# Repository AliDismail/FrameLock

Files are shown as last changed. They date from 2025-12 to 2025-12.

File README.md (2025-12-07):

# FrameLock

## About

FrameLock is a lightweight autonomous mobile robot designed to act as a smart camera operator and mobile assistant, integrating real-time face tracking, automatic centering, and adaptive motion.  
This project proposes the design of a lightweight autonomous mobile robot that acts as both a smart camera operator and a mobile carrying  
assistant.
It integrates real-time face tracking, automatic centering, and smooth mobility to follow the user without any manual control.

---

## Versions

### Version 1

-   Autonomous subject tracking and centering using face recognition
-   Mobile platform capable of carrying items (equipment, tools, camera gear…)
-   Adaptive by maintaining distance & adjusting speed
-   Stable motion with PID and balanced chassis design
-   Fully standalone system that requires no intervention
-   Sleek and rigid design for portability

### Version 2 (Work in Progress)

- Current development branch focuses on implementing a low level PID controller on each motor to ensure correct input to output behavior.
- Goal: improve stability
- Work in progress: adapting the machine logic and hardware include the digital encoder for each motor
- Not yet fully documented or tested.

## Status

- ✅ Version 1  complete and documented.
- 🚧 Version 2  under development.

---

## Team Members

- Version 1: Ali Ismail, Nour Zebian, Farah Mikheal
- Version 2: Ali Ismail, Nour Zebian, Farah Mikheal

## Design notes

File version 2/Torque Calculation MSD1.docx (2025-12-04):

# Torque Calculation for 6 kg Robot on Tiles

Estimating the required torque for robot’s displacement to be close to human pace while tracking, we used:

• Mass m = 6 kg

• Ground: flat terrain

• Number of driven wheels = 2

• Wheel radius r = 0.065 m (130 mm diameter)

• Chosen linear acceleration a ≈ 0.3 m/s²

1. Acceleration force:

F_acc = m · a = 6 × 0.3 = 1.8 N

2. Rolling resistance on tiles (C_rr ≈ 0.02):

F_rr = C_rr · m · g = 0.02 × 6 × 9.81 ≈ 1.18 N

3. Total drive force:

F_total ≈ F_acc + F_rr ≈ 1.8 + 1.18 ≈ 3.0 N

4. Torque at the wheels:

T_total = F_total · r = 3.0 × 0.065 ≈ 0.195 N·m

5. Torque per motor (with 2 driven wheels):

T_per_motor ≈ T_total / 2 ≈ 0.195 / 2 ≈ 0.0975 N·m ≈ 0.1 N·m

Therefore, each motor should be able to provide about 0.1 N·m of continuous torque. For this, we selected the motors with a safety factor of around 2, this value as stall torque to ensure a safe margin.

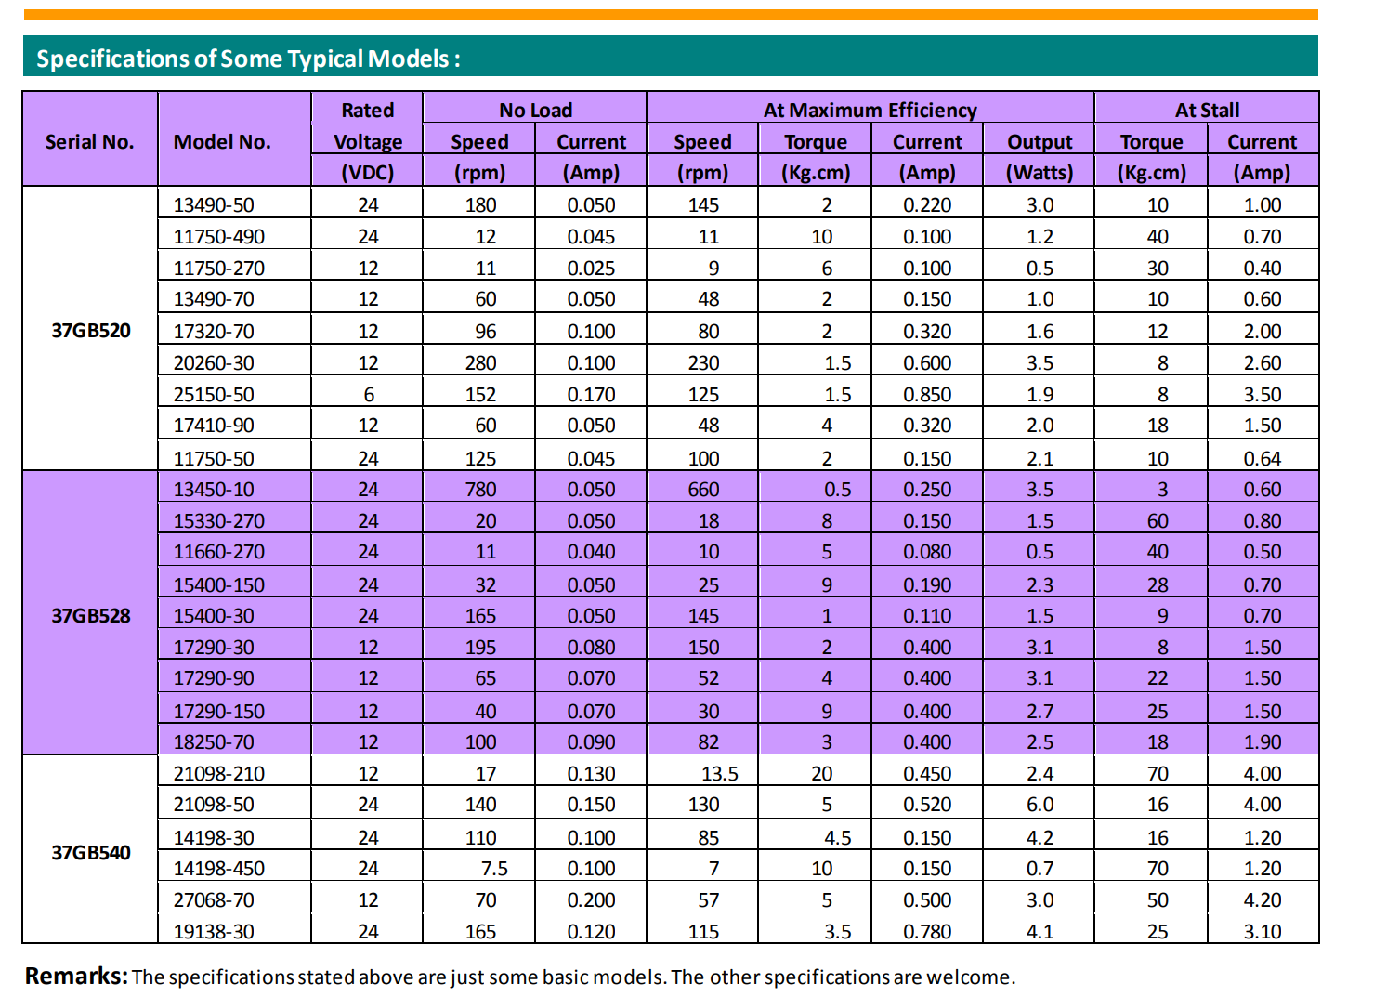
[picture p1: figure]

PWM duty (d) | Approx. torque (T(d))
30% | 0.059 N·m
40% | 0.078 N·m
50% | 0.098 N·m (just below required)
60% | 0.118 N·m
70% | 0.137 N·m
80% | 0.157 N·m
90% | 0.176 N·m
100% | 0.196 N·m

We need around 0.1N.m

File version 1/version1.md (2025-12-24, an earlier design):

# FrameLock

## Introduction

Capturing smooth video shots is challenging, especially when filming solo. FrameLock is a lightweight autonomous mobile robot designed to act as a smart camera operator and mobile assistant, integrating real-time face tracking, automatic centering, and adaptive motion.  
This project proposes the design of a lightweight autonomous mobile robot that acts as both a smart camera operator and a mobile carrying  
assistant.
It integrates real-time face tracking, automatic centering, and smooth mobility to follow the user without any manual control.

The robot:

- Autonomous subject tracking and centering using face recognition
- Mobile platform capable of carrying items (equipment, tools, camera gear…)
- Adaptive by maintaining distance & adjusting speed
- Stable motion with PID and balanced chassis design
- Fully standalone system that requires no intervention
- Sleek and rigid design for portability

---

## Equipment

- MG90S servo motor
- Arduino kit remote control
- IR receiver module
- Arduino UNO R3
- Raspberry Pi 5 8GB ram
- L298N motor driver
- 37GB528 DC motor
- WS2812B RGB Neopixel LED Ring
- GY-30 BH1750 intensity light sensor
- Raspberry Pi5 official case
- Type C 5V/5A output power bank

---

## Design Summary

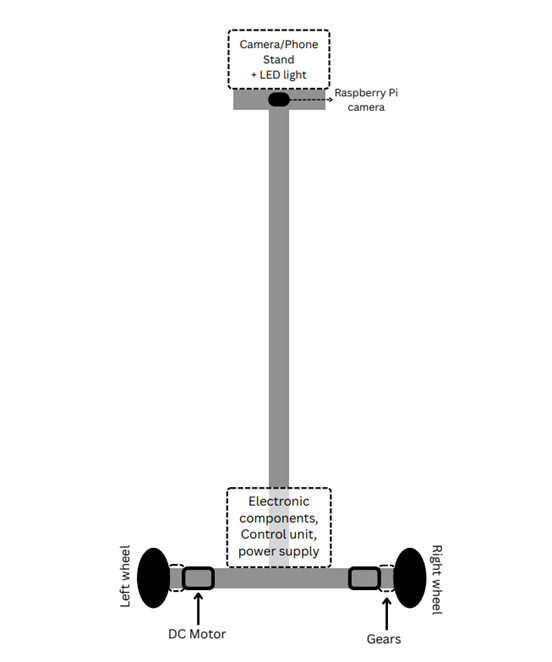
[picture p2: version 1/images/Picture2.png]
Figure 1: Theoretical Concept


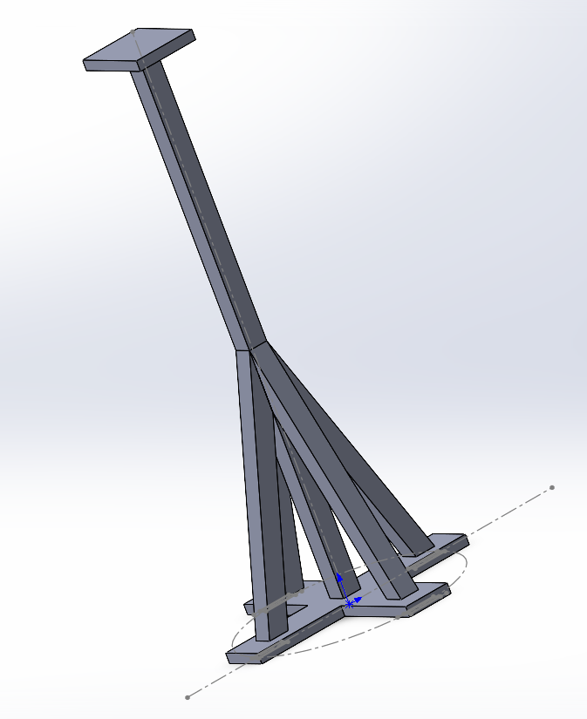
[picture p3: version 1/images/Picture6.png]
Figure 2: CAD Prototype


Our project is lightweight autonomous mobile tripod robot that can:

- Recognize authorized faces
- Choose the face to follow
- Center the face and the camera
- Maintain a certain distance between the camera and the face

---

## System Details

Our design went through many theoretical solutions and we choose an optimal solution out of them after testing in simulations which one we should use.
The solution we choose highlighted in the table:
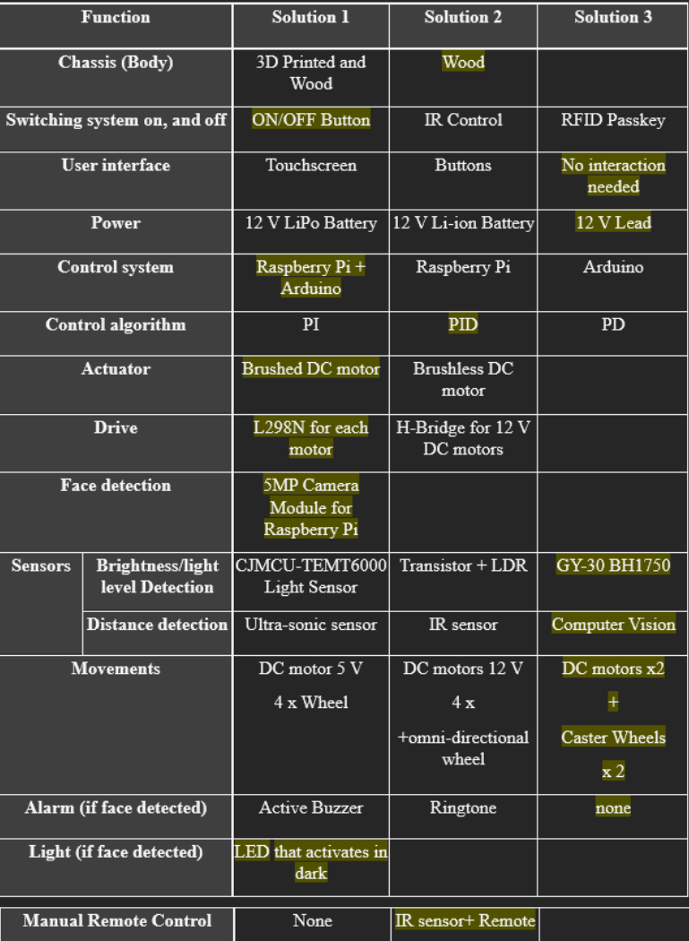
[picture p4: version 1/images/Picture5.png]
Figure 3: Optimal Solution Table

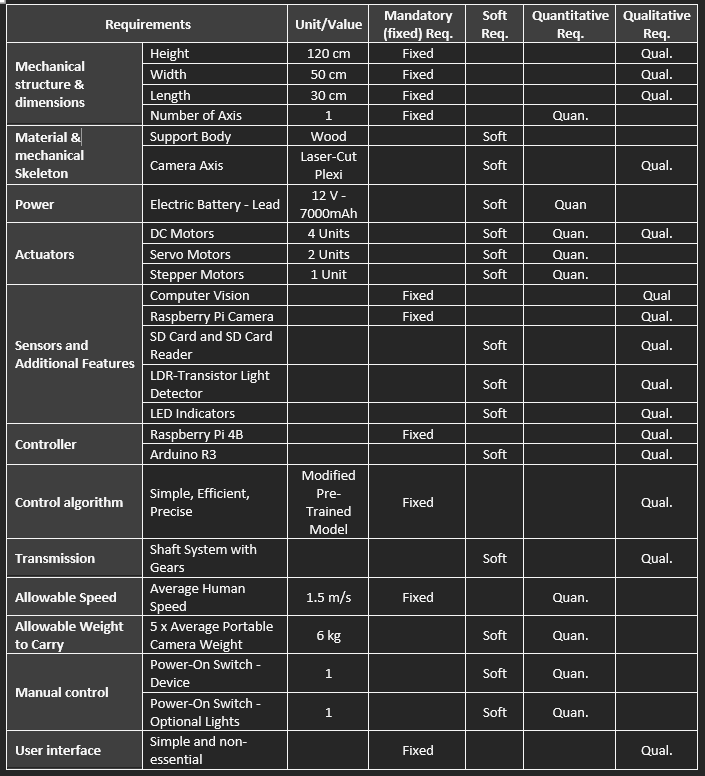
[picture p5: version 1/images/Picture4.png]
Figure 3.5: Optimal Solution Table


### Design

- **Main Body**: Constructed from wood to provide a strong yet lightweight frame, with an integrated compartment dedicated to housing the battery.
- **Electronics Housing**: A custom case was fabricated for both the power bank and the Raspberry Pi 5. Reinforced cardboard was used for durability, and the case was securely mounted onto the wooden structure.
- **Wiring System**: Extended custom-built wiring harnesses (female-to-male and female-to-female connectors) were created to bridge the long distance between the Raspberry Pi and the motors, ensuring reliable connectivity and flexibility in component placement.

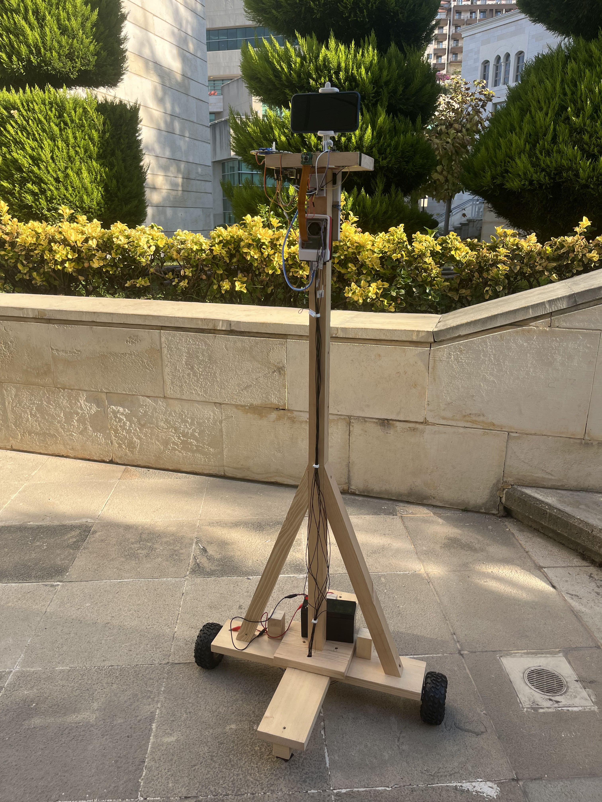
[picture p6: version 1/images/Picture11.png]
Figure 4: Main Body


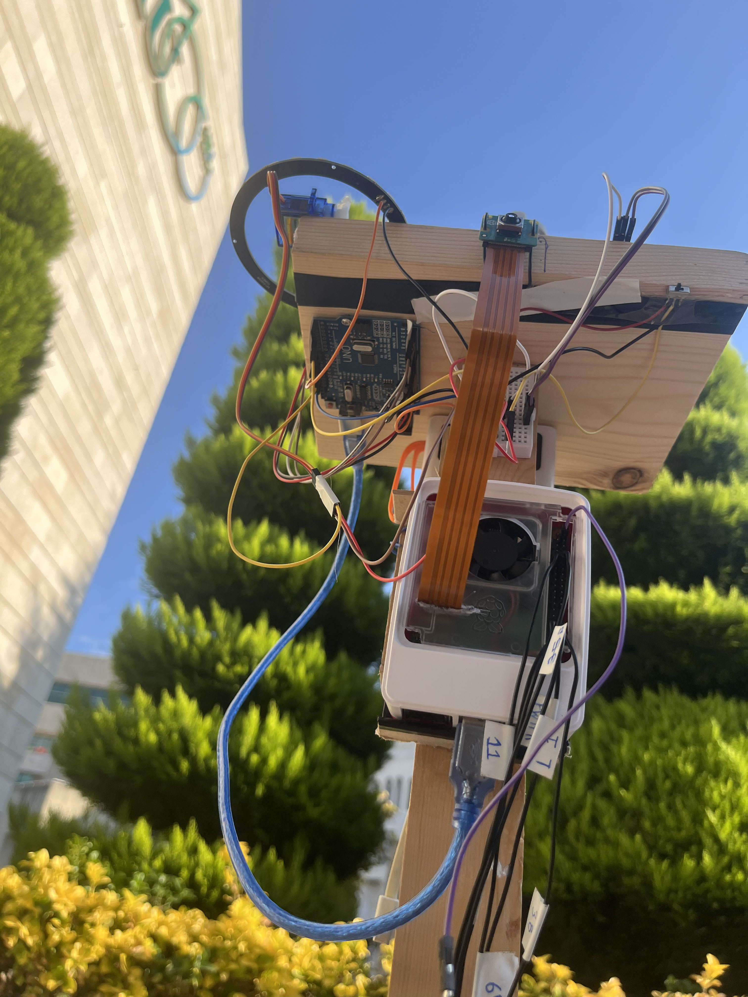
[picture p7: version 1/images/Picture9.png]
Figure 5: Pi5 Case


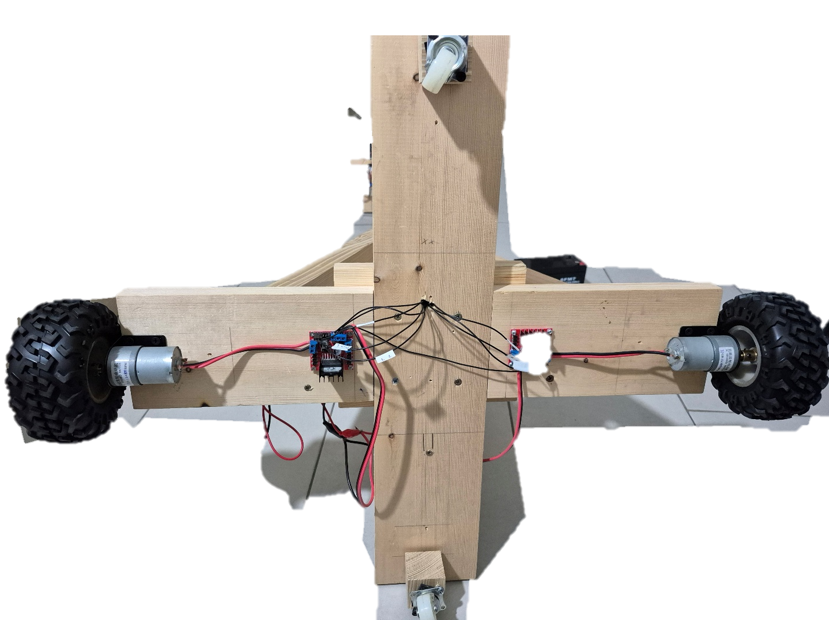
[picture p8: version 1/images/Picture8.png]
Figure 6: Motor Setup


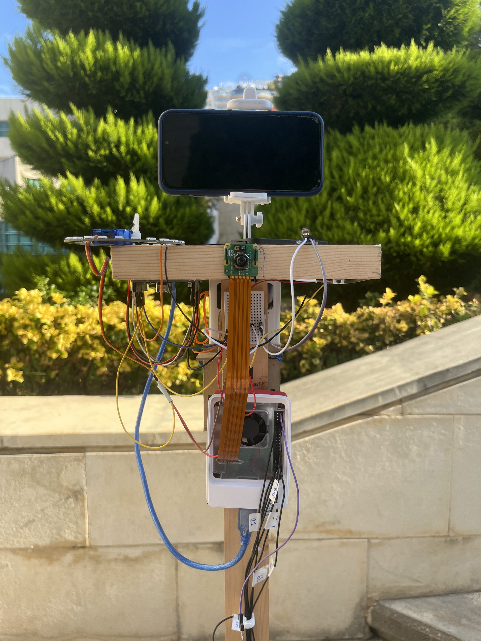
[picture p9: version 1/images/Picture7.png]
Figure 7: Arduino Setup


### Circuit

**Pi5 Connections:**

- DC motor 1 + L298N motor driver 1
  - IN1: GPIO16 | pin 36
  - IN2: GPIO 17 | pin 11
  - ENB: GPI 18 | pin 12
- DC motor 2 + L298N motor driver 2
  - IN1: GPIO16 | pin 36
  - IN2: GPIO 17 | pin 11
  - ENB: GPI 18 | pin 12
- Pi camera
- Arduino | USB A port

**Arduino Connections**

- Servo motor | pin 9
- LED ring | pin 6
- IR receiver | pin 11

---

## Code

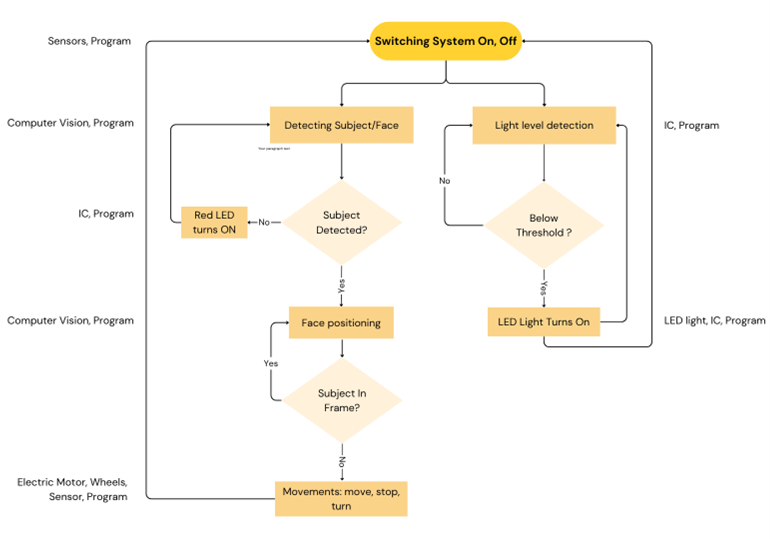
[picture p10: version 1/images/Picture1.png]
Figure 8: Logic Diagram


The robot’s behavior is governed by a structured loop that integrates **IR input**, **computer vision**, and **motor control**:

### Control Logic

1.  **User Input Phase**
    - The system waits for a command via the IR receiver, specifying which face to track.
2.  **Centering Phase**
    - Once the face is identified, the robot continuously adjusts its orientation to align the face with the center of the camera’s field of view using a PID algorithm.
3.  **Distance Maintenance Phase**
    - When the face is centered, the robot regulates its position to maintain a predefined distance between the camera and the subject using a PID algorithm.
    - If the face drifts off-center, the robot re-enters the centering phase before resuming distance regulation.

### Note

To run the code you need to write this commands in the terminal:

1. Create a virtual environment
   ```
   python3 -m venv face_rec
   ```
2. Place the requirements file inside the venv you created
3. download the libraries using the requirements file
   ```
   source  face_rec/bin/activate
   pip install -r requirements.txt
   ```

---

## Team Members

Ali Ismail - Control System, CV & Integration, Arduino Development

Farah Michael - Mechanical Design, Arduino Development

Nour Zebian - Mechanical Design, CV & Integration

## Sources
Demo Video:
https://youtube.com/shorts/7iFiCQCnec0

PID Controller Library:

- Motor Speed Controller:
  https://thingsdaq.org/2022/04/17/motor-speed-control-with-raspberry-pi/
- Gpiozero Extended Library:
  https://github.com/EduardoNigro/Things-DAQ-Code/blob/main/Motor-Speed-Control/gpiozero_extended.py

Facial Recognition with OpenCV:

- Written Tutorial:
  https://core-electronics.com.au/guides/raspberry-pi/face-recognition-with-raspberry-pi-and-opencv/
- YouTube Tutorial:
  https://www.youtube.com/watch?v=3TUlJrRJUeM

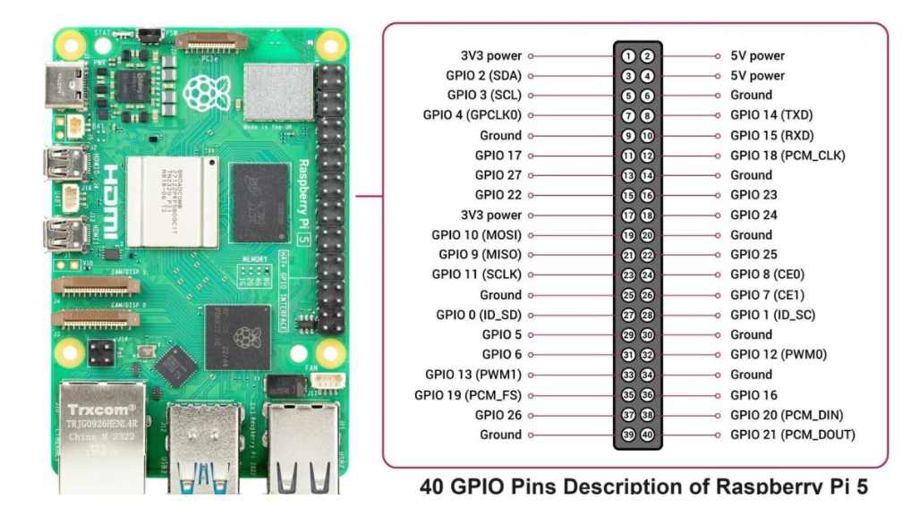
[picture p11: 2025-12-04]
version 2/datasheet/pins.png

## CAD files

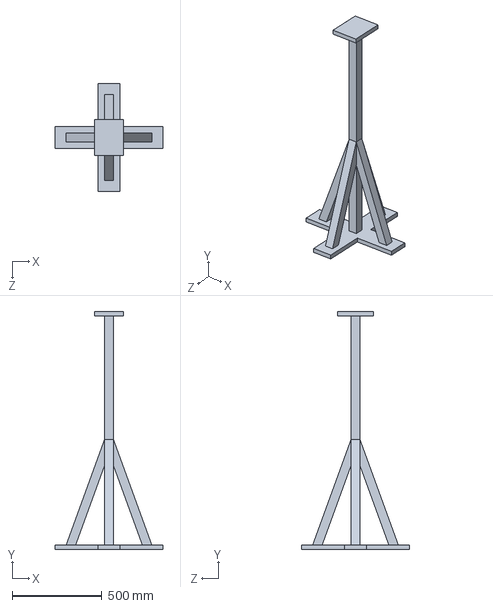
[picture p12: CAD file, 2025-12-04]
version 2/design/MSD1 project.SLDPRT
600.0 x 1325.0 x 600.0 mm

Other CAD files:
version 1/design/MSD1 project.SLDDRW
version 2/design/MSD1 project.SLDDRW

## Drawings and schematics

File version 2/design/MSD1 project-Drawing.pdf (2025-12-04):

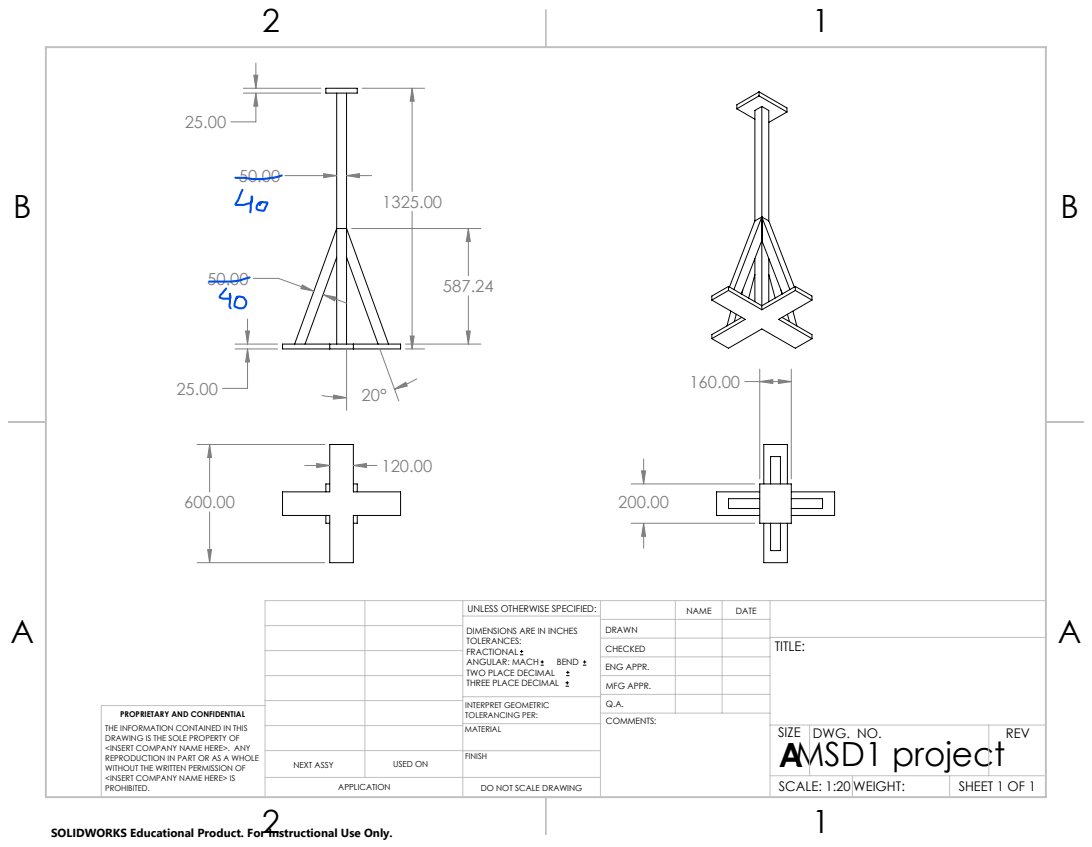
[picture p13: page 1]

UNLESS OTHERWISE SPECIFIED: | | NAME | DATE
DIMENSIONS ARE IN INCHES TOLERANCES: FRACTIONAL ANGULAR: MACH BEND TWO PLACE DECIMAL THREE PLACE DECIMAL | DRAWN

CHECKED | | | TITLE:

ENG APPR.
MFG APPR.

INTERPRET GEOMETRIC TOLERANCING PER: | Q.A.
MATERIAL | | SIZE A MSD1 project | DWG. NO. | REV

PROPRIETARY AND CONFIDENTIAL
THE INFORMATION CONTAINED IN THIS
DRAWING IS THE SOLE PROPERTY OF
<INSERT COMPANY NAME HERE>. ANY
REPRODUCTION IN PART OR AS A WHOLE
WITHOUT THE WRITTEN PERMISSION OF
<INSERT COMPANY NAME HERE> IS
PROHIBITED.

NEXT ASSY | USED ON | FINISH

APPLICATION | DO NOT SCALE DRAWING | | SCALE: 1:20 WEIGHT: | | SHEET 1 OF 1

SOLIDWORKS Educational Product. For Instructional Use Only.

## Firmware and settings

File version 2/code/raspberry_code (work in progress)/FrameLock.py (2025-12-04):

import face_recognition
import cv2
import numpy as np
from picamera2 import Picamera2
import time
import pickle
import threading
import serial
from gpiozero_extended import Motor, PID

# List of names that will trigger the GPIO pin (case-sensitive)
authorized_names = ["Ali Ismail", "Nour Zebian", "Farah Micheal", "Maher AlRafei"]

# Map IR keys to names (edit to match your encodings.pickle order or preferences)
IR_BUTTON_TO_NAME = {
    "KEY_0": "Ali Ismail",
    "KEY_1": "Nour Zebian",
    "KEY_2": "Farah Micheal",
    "KEY_3": "Maher AlRafei",
    # extend as needed:
    # "KEY_4": "Someone Else",
    # "KEY_5": "...",
    # ...
}

# ------------------------------
# Serial IR selector (Arduino → Pi)
# ------------------------------
class SerialIRSelector:
    def __init__(self, tracker, port="/dev/ttyUSB0", baud=9600):
        self.tracker = tracker
        self.port = port
        self.baud = baud
        self._stop = threading.Event()
        self._thread = None
        self._ser = None

    def start(self):
        try:
            self._ser = serial.Serial(self.port, self.baud, timeout=0.1)
            print(f"[IR] Connected to {self.port} @ {self.baud}")
        except Exception as e:
            print(f"[IR][WARN] Could not open serial port {self.port}: {e}")
            self._ser = None
            return

        self._thread = threading.Thread(target=self._loop, daemon=True)
        self._thread.start()

    def _loop(self):
        while not self._stop.is_set():
            try:
                if self._ser and self._ser.in_waiting > 0:
                    code = self._ser.readline().decode(errors="ignore").strip()
                    if code:
                        # Expecting strings like "KEY_0" .. "KEY_9" from Arduino
                        if code in IR_BUTTON_TO_NAME:
                            target = IR_BUTTON_TO_NAME[code]
                            self.tracker.set_target(target)
                            print(f"[IR] {code} → target set: {target}")
                        else:
                            print(f"[IR] Unmapped code: {code}")
            except Exception as e:
                print(f"[IR][ERR] Serial read error: {e}")
                time.sleep(0.1)
            time.sleep(0.01)

    def stop(self):
        self._stop.set()
        if self._thread:
            self._thread.join(timeout=1.0)
        if self._ser:
            try:
                self._ser.close()
            except:
                pass


# ------------------------------
# Vision: face detection + distance + overlay
# ------------------------------
class FaceLocation:
    def __init__(self,
                 encoding_file="encodings.pickle",
                 tolerance=0.1,
                 target_face_height_norm=0.25,
                 distance_tolerance_norm=0.03,
                 reference_distance_m=1.0,
                 cv_scaler=4):
        self.tolerance = tolerance
        self.TARGET_FACE_HEIGHT_NORM = target_face_height_norm
        self.DISTANCE_TOLERANCE_NORM = distance_tolerance_norm
        self.REFERENCE_DISTANCE_M = reference_distance_m
        self.cv_scaler = cv_scaler

        print("[INFO] loading encodings...")
        with open(encoding_file, "rb") as f:
            data = pickle.loads(f.read())
        self.known_face_encodings = data["encodings"]
        self.known_face_names = data["names"]

        self.picam2 = Picamera2()
        self.picam2.configure(self.picam2.create_preview_configuration(
            main={"format": 'XRGB8888', "size": (1920, 1080)}
        ))
        self.picam2.start()

        self.face_locations = []
        self.face_names = []
        self.target_name = None  # chosen face to follow

    def set_target(self, name):
        """Choose which face to follow by name."""
        if name in self.known_face_names:
            self.target_name = name
            print(f"[INFO] Target face set to: {name}")
        else:
            print(f"[WARN] {name} not in known faces. Known: {self.known_face_names}")

    def clear_target(self):
        self.target_name = None
        print("[INFO] Target face cleared")

    def process_frame(self, frame):
        resized = cv2.resize(frame, (0, 0), fx=1/self.cv_scaler, fy=1/self.cv_scaler)
        rgb = cv2.cvtColor(resized, cv2.COLOR_BGR2RGB)

        self.face_locations = face_recognition.face_locations(rgb)
        encodings = face_recognition.face_encodings(rgb, self.face_locations)

        self.face_names = []
        for encoding in encodings:
            matches = face_recognition.compare_faces(self.known_face_encodings, encoding)
            name = "Unknown"
            if matches:
                distances = face_recognition.face_distance(self.known_face_encodings, encoding)
                best = np.argmin(distances)
                if matches[best]:
                    name = self.known_face_names[best]
            self.face_names.append(name)

    def get_distance_from_camera(self, frame):
        results = []
        h, w = frame.shape[:2]
        for (top, right, bottom, left), name in zip(self.face_locations, self.face_names):
            top *= self.cv_scaler
            bottom *= self.cv_scaler
            face_height = bottom - top
            norm_height = face_height / h
            safe_height = max(norm_height, 1e-6)
            distance_m = self.REFERENCE_DISTANCE_M * (self.TARGET_FACE_HEIGHT_NORM / safe_height)

            if safe_height < (self.TARGET_FACE_HEIGHT_NORM - self.DISTANCE_TOLERANCE_NORM):
                state = "FAR"
            elif safe_height > (self.TARGET_FACE_HEIGHT_NORM + self.DISTANCE_TOLERANCE_NORM):
                state = "CLOSE"
            else:
                state = "OK"

            results.append((name, distance_m, state))
        return results

    def get_recognized_names(self):
        if self.target_name:
            return [name for name in self.face_names if name == self.target_name]
        else:
            return [name for name in self.face_names if name in authorized_names]

    def get_face_deviation(self, frame):
        """Return signed deviation from center [-0.5, +0.5] for the target (or first authorized)."""
        if not self.face_locations:
            return None
        h, w = frame.shape[:2]

        # pick target face if set, else first authorized
        idx = None
        if self.target_name and self.target_name in self.face_names:
            idx = self.face_names.index(self.target_name)
        else:
            for i, nm in enumerate(self.face_names):
                if nm in authorized_names:
                    idx = i
                    break
        if idx is None:
            return None

        (top, right, bottom, left) = self.face_locations[idx]
        top *= self.cv_scaler
        right *= self.cv_scaler
        bottom *= self.cv_scaler
        left *= self.cv_scaler
        center_x = (left + right) / 2.0
        norm_x = center_x / w
        deviation = norm_x - 0.5
        return deviation

    def annotate_frame(self, frame):
        h, w = frame.shape[:2]
        mid_x = w // 2
        cv2.line(frame, (mid_x, 0), (mid_x, h), (255, 0, 0), 2)

        for (top, right, bottom, left), name in zip(self.face_locations, self.face_names):
            top *= self.cv_scaler
            right *= self.cv_scaler
            bottom *= self.cv_scaler
            left *= self.cv_scaler

            face_height = bottom - top
            norm_height = face_height / h
            safe_height = max(norm_height, 1e-6)
            distance_m = self.REFERENCE_DISTANCE_M * (self.TARGET_FACE_HEIGHT_NORM / safe_height)

            center_x = (left + right) / 2.0
            norm_x = center_x / w
            deviation = norm_x - 0.5
            if abs(deviation) < self.tolerance:
                position = "CENTER"
            elif deviation < 0:
                position = "LEFT"
            else:
                position = "RIGHT"

            # highlight target in green, authorized in cyan, unknown in red
            if name == self.target_name:
                color = (0, 255, 0)
            elif name in authorized_names:
                color = (255, 255, 0)
            else:
                color = (0, 0, 255)

            cv2.rectangle(frame, (left, top), (right, bottom), color, 2)
            label = f"{name} | {distance_m:.2f}m | {position} ({deviation:.2f})"
            cv2.rectangle(frame, (left, top - 25), (right, top), color, cv2.FILLED)
            cv2.putText(frame, label, (left + 6, top - 6),
                        cv2.FONT_HERSHEY_DUPLEX, 0.6, (255, 255, 255), 1)
        return frame

    def cleanup(self):
        cv2.destroyAllWindows()
        self.picam2.stop()


# ------------------------------
# Motor control for distance (forward/backward)
# ------------------------------
class Motor_Control:
    def __init__(self,
                 left_pins,
                 right_pins,
                 kp, ki, kd,
                 Ts=0.05, tau=0.1,
                 setpoint=1.0, tolerance=1e-3,
                 min_torque=0.35, startup_boost_time=0.15,
                 tracker: FaceLocation = None):
        self.motor_left = Motor(enable1=left_pins[0], pwm1=left_pins[1], pwm2=left_pins[2])
        self.motor_right = Motor(enable1=right_pins[0], pwm1=right_pins[1], pwm2=right_pins[2])

        self.Ts = Ts
        self.pid = PID(Ts, kp, ki, kd, tau=tau)

        self.setpoint = setpoint
        self.tolerance = tolerance
        self.min_torque = min_torque
        self.startup_boost_time = startup_boost_time

        # Reuse the shared tracker to avoid multiple camera instances
        self.tracker = tracker

        self._start_time = time.perf_counter()

    def step_distance_control(self, frame):
        distances = self.tracker.get_distance_from_camera(frame)
        recognized = self.tracker.get_recognized_names()

        if not distances or not recognized:
            print("No target/authorized face detected. Stopping motors.")
            self.motor_left.set_output(0)
            self.motor_right.set_output(0)
            return

        # pick the target’s distance
        name_to_follow = self.tracker.target_name if self.tracker.target_name else recognized[0]
        distance = None
        for nm, dist, _ in distances:
            if nm == name_to_follow:
                distance = dist
                break

        if distance is None:
            self.motor_left.set_output(0)
            self.motor_right.set_output(0)
            return

        error = self.setpoint - distance

        if abs(error) > self.tolerance:
            output = self.pid.control(self.setpoint, distance)

            # Startup boost to overcome static friction
            elapsed = time.perf_counter() - self._start_time
            if elapsed < self.startup_boost_time:
                output = 1.0

            # Minimum torque floor
            if abs(output) < self.min_torque:
                output = self.min_torque * (1 if output >= 0 else -1)

            # Apply forward/backward equally
            self.motor_left.set_output(output)
            self.motor_right.set_output(output)
        else:
            self.motor_left.set_output(0)
            self.motor_right.set_output(0)
            print(f"Target distance {self.setpoint:.2f} m maintained.")


# ------------------------------
# Hybrid controller (centering priority, then distance)
# ------------------------------
class HybridController:
    def __init__(self,
                 left_pins, right_pins,
                 kp_dist, ki_dist, kd_dist,
                 kp_cen, ki_cen, kd_cen,
                 Ts=0.05, tau=0.1, setpoint=1.0,
                 ir_port="/dev/ttyUSB0"):
        # Shared vision tracker
        self.tracker = FaceLocation()

        # Start IR selector thread
        self.ir_selector = SerialIRSelector(self.tracker, port=ir_port, baud=9600)
        self.ir_selector.start()

        # PID controllers
        self.center_pid = PID(Ts, kp_cen, ki_cen, kd_cen, tau=tau)
        self.distance_ctrl = Motor_Control(left_pins, right_pins,
                                           kp=kp_dist, ki=ki_dist, kd=kd_dist,
                                           Ts=Ts, tau=tau, setpoint=setpoint,
                                           tracker=self.tracker)

        # Direct motor handles
        self.motor_left = self.distance_ctrl.motor_left
        self.motor_right = self.distance_ctrl.motor_right

        # Tolerances and floors
        self.deviation_tolerance = 0.05      # center tolerance (normalized x)
        self.min_spin_floor = 0.40           # spin-in-place floor
        self.center_startup_boost_time = 0.20

        # Timing
        self.Ts = Ts
        self._center_start = time.perf_counter()

    def run(self):
        try:
            while True:
                frame = self.tracker.picam2.capture_array()
                self.tracker.process_frame(frame)

                deviation = self.tracker.get_face_deviation(frame)
                recognized = self.tracker.get_recognized_names()

                if (self.tracker.target_name and self.tracker.target_name not in self.tracker.face_names):
                    print("Target not visible or no authorized face detected.")
                    self.motor_left.set_output(0)
                    self.motor_right.set_output(0)
                elif deviation is not None and abs(deviation) > self.deviation_tolerance:
                    # Centering mode (higher priority)
                    output = self.center_pid.control(0.0, deviation)

                    # Startup boost for centering
                    elapsed_c = time.perf_counter() - self._center_start
                    if elapsed_c < self.center_startup_boost_time:
                        output = 1.0

                    # Minimum spin torque floor
                    if abs(output) < self.min_spin_floor:
                        output = self.min_spin_floor * (1 if output >= 0 else -1)

                    # Spin in place to reduce horizontal error
                    self.motor_left.set_output(-output)
                    self.motor_right.set_output(output)
                else:
                    # Distance maintaining mode
                    self.distance_ctrl.step_distance_control(frame)

                # Show annotated feed
                annotated = self.tracker.annotate_frame(frame)
                cv2.imshow("Hybrid Face Tracking (IR-selectable target)", annotated)
                if cv2.waitKey(1) & 0xFF == ord('q'):
                    break

                time.sleep(self.Ts)
        finally:
            # Safe shutdown
            self.motor_left.set_output(0)
            self.motor_right.set_output(0)
            self.ir_selector.stop()
            self.tracker.cleanup()
            cv2.destroyAllWindows()


# ------------------------------
# Main: hard-coded values for your 37GB528 + L298N + ~5 kg robot
# ------------------------------
def main():
    # Motor pins (enable1, pwm1, pwm2)
    left_pins = (16, 17, 18)
    right_pins = (19, 20, 21)

    # Control timing and filter
    Ts = 0.05      # 20 Hz control loop (good for vision + L298N)
    tau = 0.10     # derivative low-pass

    # Target distance (meters)
    setpoint = 1.0

    # Distance PID (balanced)
    kp_dist = 0.55; ki_dist = 0.12; kd_dist = 0.04

    # Centering PID (balanced)
    kp_cen = 0.65; ki_cen = 0.15; kd_cen = 0.04

    # Set the serial port to your Arduino (check with ls /dev/ttyUSB* or /dev/ttyACM*)
    ir_port = "/dev/ttyUSB0"

    hybrid_ctrl = HybridController(
        left_pins=left_pins,
        right_pins=right_pins,
        kp_dist=kp_dist, ki_dist=ki_dist, kd_dist=kd_dist,
        kp_cen=kp_cen, ki_cen=ki_cen, kd_cen=kd_cen,
        Ts=Ts, tau=tau, setpoint=setpoint,
        ir_port=ir_port
    )

    print(f"Starting hybrid control with:"
          f" dist(kp={kp_dist}, ki={ki_dist}, kd={kd_dist}),"
          f" cen(kp={kp_cen}, ki={ki_cen}, kd={kd_cen}),"
          f" Ts={Ts}, tau={tau}, setpoint={setpoint}m")
    print("Use IR remote keys (KEY_0..KEY_3) to select target face.")

    try:
        hybrid_ctrl.run()
    finally:
        print("Cleaning up...")

if __name__ == "__main__":
    main()

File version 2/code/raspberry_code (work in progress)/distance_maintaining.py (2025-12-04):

from gpiozero_extended import Motor, PID
import time
from face_distance_tracker import FaceDistanceTracker

class DualMotorDistanceController:
    def __init__(self,
                 left_pins,
                 right_pins,
                 Ts=0.05,
                 kp=0.5, ki=0.1, kd=0.05, tau=0.1,
                 setpoint=1.0, tolerance=1e-3,
                 min_torque=0.5, startup_boost_time=0.1):
        """
        Initialize two motors and PID controller for distance control.
        """
        # Motors
        self.motor_left = Motor(enable1=left_pins[0], pwm1=left_pins[1], pwm2=left_pins[2])
        self.motor_right = Motor(enable1=right_pins[0], pwm1=right_pins[1], pwm2=right_pins[2])

        # PID controller
        self.Ts = Ts
        self.pid = PID(Ts, kp, ki, kd, tau=tau)

        # Target distance and tolerance
        self.setpoint = setpoint
        self.tolerance = tolerance

        # Torque constraints
        self.min_torque = min_torque
        self.startup_boost_time = startup_boost_time

        # Vision tracker
        self.tracker = FaceDistanceTracker()

    def get_camera_distance(self):
        """
        Use FaceDistanceTracker to measure distance in meters.
        Returns the closest face distance, or None if no face.
        """
        frame = self.tracker.picam2.capture_array()
        self.tracker.process_frame(frame)
        distances = self.tracker.get_face_distance(frame)

        if distances:
            # Pick the closest face (largest bounding box height)
            closest = min(distances, key=lambda d: d[1])  # d[1] = distance_m
            name, distance_m, state = closest
            return distance_m
        else:
            return None

    def motor_control_maintaining(self):
        """
        Run dual motor control until error is within tolerance.
        """
        try:
            start_time = time.perf_counter()

            while True:
                distance = self.get_camera_distance()
                if distance is None:
                    print("No face detected. Stopping motors.")
                    self.motor_left.set_output(0)
                    self.motor_right.set_output(0)
                    break

                error = self.setpoint - distance

                if abs(error) > self.tolerance:
                    # PID control output
                    output = self.pid.control(self.setpoint, distance)

                    # --- TORQUE CONSTRAINTS ---
                    elapsed = time.perf_counter() - start_time

                    if elapsed < self.startup_boost_time:
                        # Startup boost: max output
                        output = 1.0
                    else:
                        # Enforce minimum torque floor
                        if abs(output) < self.min_torque:
                            output = self.min_torque * (1 if output >= 0 else -1)

                    # Apply to both motors (forward/backward together)
                    self.motor_left.set_output(output)
                    self.motor_right.set_output(output)

                else:
                    # Stop motors when centered
                    self.motor_left.set_output(0)
                    self.motor_right.set_output(0)
                    print(f"Target distance {self.setpoint:.2f} m reached. Stopping motors.")
                    break

                time.sleep(self.Ts)
        finally:
            # Ensure motors are stopped on exit
            self.motor_left.set_output(0)
            self.motor_right.set_output(0)
            self.tracker.cleanup()


"""
from gpiozero_extended import Motor, PID
import time

motor = Motor(enable1=16, pwm1=17, pwm2=18)

Ts = 0.05   # 50 ms loop
kp = 0.5    # proportional gain
ki = 0.1    # integral gain
kd = 0.05   # derivative gain
tau = 0.1   # low-pass filter time constant (s) f = 1/(2*pi*tau) which in this case f = 1.59 Hz

pid = PID(Ts, kp, ki, kd, tau=tau)

setpoint = 1.0  # desired distance in meters

while True:
    distance = get_camera_distance()  # <-- your OpenCV function
    output = pid.control(setpoint, distance)
    motor.set_output(output)
    time.sleep(Ts)
"""

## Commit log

2025-12-04 FrameLock first Commit
    [MSD1 project.SLDDRW, MSD1 project.SLDPRT]
2025-12-04 Rename version 1/FrameLock.md to version1.md
2025-12-04 Update design summary with new images and details
    Added additional images and expanded the wiring system description in the design summary.
2025-12-04 Change Power Bank Case image from JPG to PNG
    Updated image format for Power Bank Case.
2025-12-04 Update README with FrameLock project title
    Removed outdated project title and added FrameLock heading.
2025-12-06 Revise robot control logic and add PID details
    Updated the control logic phases for the robot's behavior, adding details on the PID algorithm for centering and distance maintenance.
